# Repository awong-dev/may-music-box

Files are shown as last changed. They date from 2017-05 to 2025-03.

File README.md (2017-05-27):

# May Music Box

This is a little project I made for my daughter. It's an
mp3 player that reads off an SD-card that's built to
replace the guts of a Munchkin Mozart Music Cube.

Why do this? Cause electronic beepy toys for toddlers
are sooo much better if you can control what gets played
on them. :)

## Features
  * Super low power draw. Inactive, draws around 210uA. Active ~50-60mA. With a 1200mAH battery, that's ~8 months of sleep (not really since the battery will leak), or 20 hours of play on one charge.
  * Hardware button debounce. Cuz I could.
  * LEDs that act ike Peak-meter to give your toddler the authentic club feel.
  * Way too much love and sweat put into buliding this thing.
  * The word "mayberry" is printed on the PCB. :)

## What's in this repository
  * Arduino sketch for the MCU that handles the input buttons and playback.
  * vdsp4 assembly code for handling mono downmix, and LED pulsing in of the VS1053b chip
  * Eagle files for the contol PCB.

## Quirks
  * There is a fork of the Adafruit vs1053b library. The mainline library has (multiple) synchronization bugs that lead to corrupted state. This fork fixes the major ones. Remove once upstream merges the fixes.

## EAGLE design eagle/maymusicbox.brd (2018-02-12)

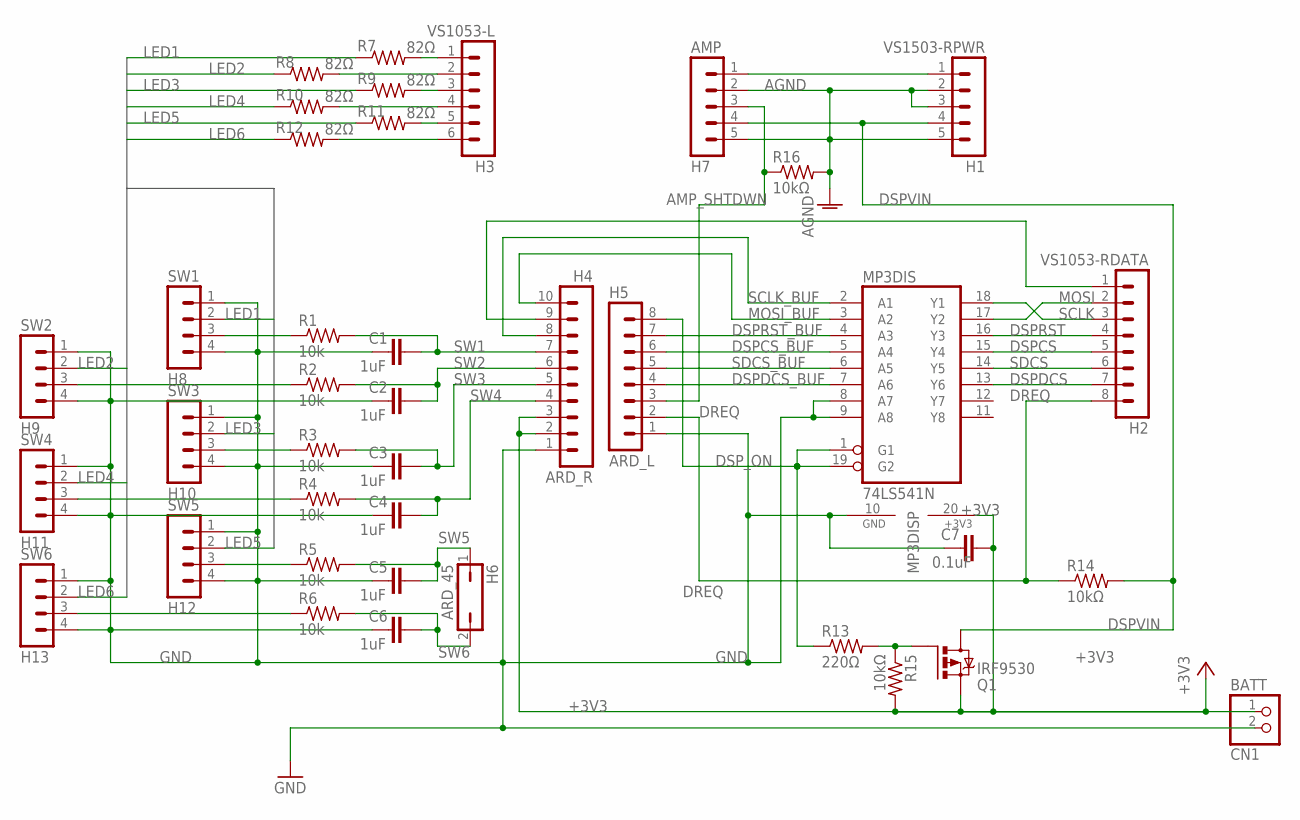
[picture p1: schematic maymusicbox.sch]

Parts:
C1, C2, C3, C4, C5, C6: 1uF; C025-025X050
C7: 0.1uF; C025-025X050
CN1: BATT; JST-PH-2-THM
H1: VS1503-RPWR; MA05-1
H2: VS1053-RDATA; MA08-1
H3: VS1053-L; MA06-1
H4: ARD_R; MA10-1
H5: ARD_L; MA08-1
H6: ARD_45; JP1
H7: AMP; MA05-1
H8: SW1; MA04-1
H9: SW2; MA04-1
H10: SW3; MA04-1
H11: SW4; MA04-1
H12: SW5; MA04-1
H13: SW6; MA04-1
MP3DIS: 74LS541N; DIL20
Q1: IRF9530; TO220BV
R1, R2, R3, R4, R5, R6: 10k; 0207/2V
R7, R8, R9, R10, R11, R12: 82Ω; 0207/2V
R13: 220Ω; 0207/2V
R14, R15, R16: 10kΩ; 0207/2V

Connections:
+3V3: C7.2, CN1.1 (2), H4.2, H4.3, MP3DIS.20 (+3V3), Q1.S, R15.2
A+: H1.1, H7.1
AGND: H1.2, H1.3, H1.5, H7.2, H7.5, R16.2
AMP_SHTDWN: H5.3, H7.3, R16.1
DREQ: H2.8, H5.2, R14.1
DSPCS: H2.5, MP3DIS.15 (Y4)
DSPCS_BUF: H5.6, MP3DIS.5 (A4)
DSPDCS: H2.7, MP3DIS.13 (Y6)
DSPDCS_BUF: H5.4, MP3DIS.7 (A6)
DSPRST: H2.4, MP3DIS.16 (Y3)
DSPRST_BUF: H5.7, MP3DIS.4 (A3)
DSPVIN: H1.4, H7.4, Q1.D, R14.2
DSP_ON: H5.8, MP3DIS.1 (G1), MP3DIS.19 (G2), R13.1
GND: C1.1, C2.1, C3.1, C4.1, C5.1, C6.1, C7.1, CN1.2 (1), H4.1, H5.1, H8.1, H8.4, H9.1, H9.4, H10.1, H10.4, H11.1, H11.4, H12.1, H12.4, H13.1, H13.4, MP3DIS.8 (A7), MP3DIS.9 (A8), MP3DIS.10 (GND)
LED1: H8.2, R7.1
LED2: H9.2, R8.1
LED3: H10.2, R9.1
LED4: H11.2, R10.1
LED5: H12.2, R11.1
LED6: H13.2, R12.1
MISO: H2.1, H4.9
MOSI: H2.2, MP3DIS.17 (Y2)
MOSI_BUF: H4.10, MP3DIS.3 (A2)
unnamed: H3.1, R7.2
unnamed: H3.2, R8.2
unnamed: Q1.G, R13.2, R15.1
unnamed: H3.3, R9.2
unnamed: H3.4, R10.2
unnamed: H3.5, R11.2
unnamed: H3.6, R12.2
unnamed: H10.3, R3.1
unnamed: H9.3, R2.1
unnamed: H8.3, R1.1
unnamed: H11.3, R4.1
unnamed: H12.3, R5.1
unnamed: H13.3, R6.1
SCLK: H2.3, MP3DIS.18 (Y1)
SCLK_BUF: H4.8, MP3DIS.2 (A1)
SDCS: H2.6, MP3DIS.14 (Y5)
SDCS_BUF: H5.5, MP3DIS.6 (A5)
SW1: C1.2, H4.7, R1.2
SW2: C2.2, H4.6, R2.2
SW3: C3.2, H4.5, R3.2
SW4: C4.2, H4.4, R4.2
SW5: C5.2, H6.1, R5.2
SW6: C6.2, H6.2, R6.2

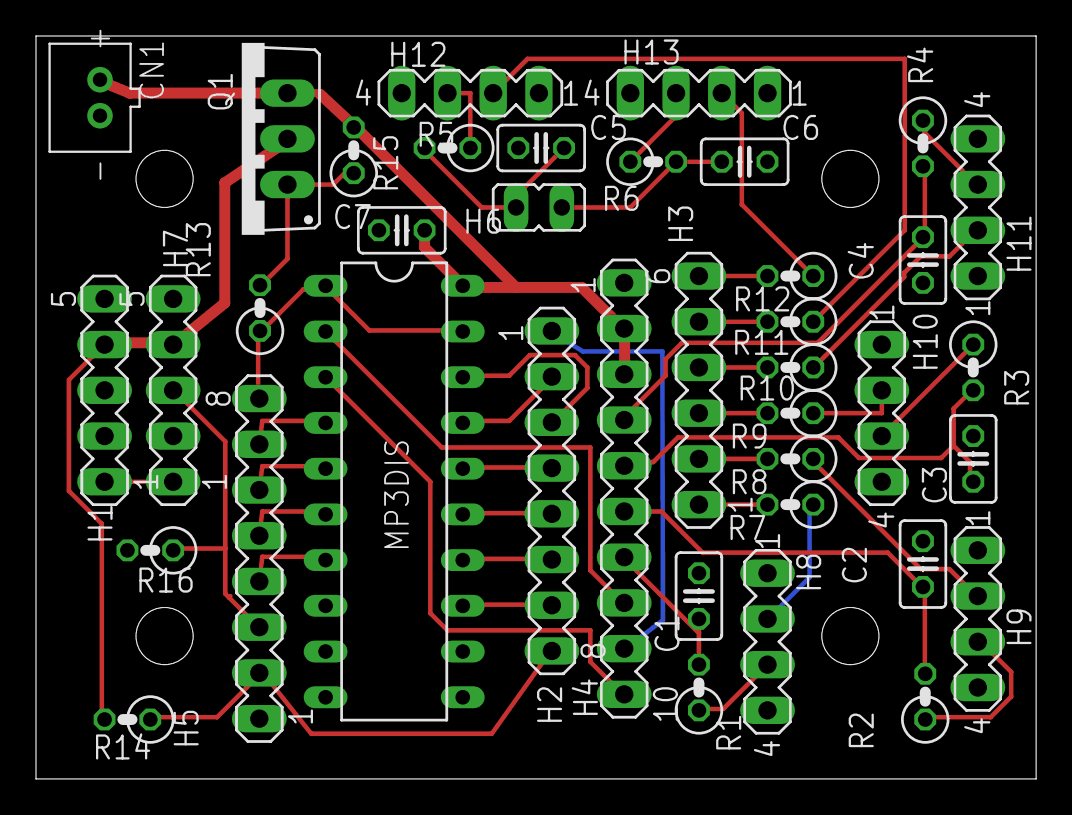
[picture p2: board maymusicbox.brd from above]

Board: 2 copper layers, 55.6 x 41.3 mm, 39 parts (0 on the bottom side), 46 nets.

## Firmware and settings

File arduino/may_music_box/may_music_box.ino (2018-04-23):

/***************************************************
  This is an example for the Adafruit VS1053 Codec Breakout

  Designed specifically to work with the Adafruit VS1053 Codec Breakout
  ----> https://www.adafruit.com/products/1381

  Adafruit invests time and resources providing this open source code,
  please support Adafruit and open-source hardware by purchasing
  products from Adafruit!

  Written by Limor Fried/Ladyada for Adafruit Industries.
  BSD license, all text above must be included in any redistribution
 ****************************************************/

// Battery Cavity:
//  2.5" deep
//  2" wide
//  0.75" tall

// include SPI, MP3 and SD libraries
#include <SPI.h>
#include <SD.h>
#include "Adafruit_VS1053.h"
#include <LowPower.h>
#include <avr/power.h>
#include <avr/sleep.h>

//#define NDEBUG 0
#define DEV_BOARD 0


#if DEV_BOARD == 0
// These are the pins used for the music maker breakout
#  define VS1053bRESET  8      // VS1053 reset pin
#  define VS1053bCS     7      // VS1053 chip select pin (output)
#  define VS1053bDCS    4      // VS1053 Data/command select pin (output)
#  define VS1053bPOWER  9      // PFET that disables VCC to shield.

// These are common pins between breakout and shield
#  define CARDCS 6     // Card chip select pin

// DREQ should be an Int pin, see http://arduino.cc/en/Reference/attachInterrupt
#  define DREQ 2       // VS1053 Data request, ideally an Interrupt pin

// AMP Controls.
#  define AMP_POWER  3         // Turn on and off the AMP before cutting power to stop "pop"
#  define AMP_SHUTDOWN_US 1000  // Microsends post shutdown switch to stablize amp.

#else 
// These are the pins used for the music maker shield
#  define VS1053bRESET  -1      // VS1053 reset pin
#  define VS1053bCS     7      // VS1053 chip select pin (output)
#  define VS1053bDCS    6      // VS1053 Data/command select pin (output)
#  define VS1053bPOWER  8      // PFET that disables VCC to shield.

// These are common pins between breakout and shield
#  define CARDCS 4     // Card chip select pin

// DREQ should be an Int pin, see http://arduino.cc/en/Reference/attachInterrupt
#  define DREQ 3       // VS1053 Data request, ideally an Interrupt pin

#  define AMP_POWER  2         // Turn on and off the AMP before cutting power to stop "pop"
#  define AMP_SHUTDOWN_US 1000  // Microsends post shutdown switch to stablize amp.
#endif


#ifdef NDEBUG
#  define DEBUG_PRINT(x, ...)
#  define DEBUG_PRINTLN(x, ...)
#else
#  define DEBUG_PRINT(x, args...) Serial.print(x, ##args)
#  define DEBUG_PRINTLN(x, args...) Serial.println(x, ##args)
#endif

Adafruit_VS1053_FilePlayer musicPlayer =
  Adafruit_VS1053_FilePlayer(VS1053bRESET, VS1053bCS, VS1053bDCS, DREQ, CARDCS);
static boolean isDspOn = false;
static volatile boolean isSdInit = false;

#define NUM_SONGS 6
static const char* files[NUM_SONGS] = {
  "p.mp3",
  "b.mp3",
  "o.mp3",
  "y.mp3",
  "r.mp3",
  "g.mp3",
};

// Button control inputs
#define RED_BUTTON A5
#define GREEN_BUTTON A4
#define YELLOW_BUTTON A3
#define PURPLE_BUTTON A2
#define BLUE_BUTTON A1
#define ORANGE_BUTTON A0

// LED map, cause I wired one of the harnesses wrong. grr. argh.
const int buttonLedMap[6] = {
  0,  // Red
  1,  // Green
  2,  // Yellow
  3,  // Orange
  5,  // Blue
  4,  // Purple
};


enum PLayCommand {
  NO_COMMAND = 0,
  PLAY_SONG = 1,
};
static volatile byte playCommand = PLAY_SONG;
static volatile unsigned char commandCount = 0;
static volatile byte buttonState = 0;

ISR(PCINT1_vect) {
  byte newButtonState = PINC;
  // Interrupts are triggered on down and up edges. Ignore when everything is up.
  if ((newButtonState & 0x3F) != 0x3F) {
    playCommand = PLAY_SONG;
    buttonState = newButtonState;
    commandCount = commandCount + 1;
  }
  PCICR &= ~_BV(1);
}

//// VS1053b

#define SKIP_PLUGIN_VARNAME
const PROGMEM uint16_t vs1053b_patches[] = { 
//#include "/Users/awong/Desktop/vlsi/awong-ledtest/ledtest-plugin.h"
#include "/Users/awong/Desktop/vlsi/may-music/may-music-vs1053b-plugin.h"
};
#undef SKIP_PLUGIN_VARNAME

////

static void ErrorSleepForever(void);

static void inline PowerOnDsp(void) {
  isDspOn = true;
  
  digitalWrite(AMP_POWER, HIGH);
  delayMicroseconds(AMP_SHUTDOWN_US);
  DEBUG_PRINTLN(F("AMP Powered On"));

  digitalWrite(VS1053bPOWER, LOW);
  // Per VS1053 10.2, Hardware Reset, DREQ is low for about 22000 clocks.
  // At 12Mhz, that's 1.8ms. Give 4 just for good measure.
  delay(4);
  DEBUG_PRINTLN(F("DSP Powered On"));

  initMp3Shield();
}

static void inline PowerOffDsp(void) {
  DEBUG_PRINTLN("DSP Powered Off");
  /* Turn on MP3 shield */
  detachInterrupt(DREQ);
  digitalWrite(AMP_POWER, LOW);
  delayMicroseconds(AMP_SHUTDOWN_US);
  digitalWrite(VS1053bPOWER, HIGH);
  isDspOn = false;
}

static void initMp3Shield() {
  // initialise the music player
  if (!musicPlayer.begin()) {
    DEBUG_PRINTLN(F("Couldn't find VS1053, do you have the right pins defined?"));
    while(1);
    ErrorSleepForever();
  }
  DEBUG_PRINTLN(F("VS1053 found"));

  // Set volume for left, right channels. lower numbers == louder volume!
  // 90 seems like a good amplified volume.
  enum {
    VOL_INSANE = 10, // 70mA during playback.  .21mA sleeping.
    VOL_HIGH = 20,
    VOL_NORMAL = 25,  // Emprical testing for "loud enough"
    VOL_MED = 90,   // Seems to be about 2mA less than HIGH ode.
    VOL_LOW = 120,
  };
  musicPlayer.setVolume(VOL_NORMAL, VOL_NORMAL);

  DEBUG_PRINT(F("isSdInit: "));
  DEBUG_PRINTLN(isSdInit, BIN);
  if (!SD.begin(CARDCS)) {
    if (!isSdInit) {
      DEBUG_PRINTLN(F("SD failed, or not present"));
      DEBUG_PRINTLN(F("SD failed, or not present"));
      DEBUG_PRINTLN(F("SD failed, or not present"));
      DEBUG_PRINTLN(F("SD failed, or not present"));
      ErrorSleepForever();
    }
    // Second inits always generates an error from the library, but it is required.
  } else {
    isSdInit = true;
  }
  DEBUG_PRINTLN(F("SD OK!"));

  // This option uses a pin interrupt. No timers required! But DREQ
  // must be on an interrupt pin. For Uno/Duemilanove/Diecimilla
  // that's Digital #2 or #3
  // See http://arduino.cc/en/Reference/attachInterrupt for other pins
  // *** This method is preferred
  if (!musicPlayer.useInterrupt(VS1053_FILEPLAYER_PIN_INT)) {
    DEBUG_PRINTLN(F("DREQ pin is not an interrupt pin"));
    ErrorSleepForever();
  }

  musicPlayer.applyPatch(vs1053b_patches, PLUGIN_SIZE);
  musicPlayer.sciWrite(VS1053_SCI_AIADDR, 0x50);
  delay(1);    while (! musicPlayer.readyForData() );
}

static void ErrorSleepForever(void) {
  DEBUG_PRINTLN(F("Error state. Sleep Forever"));
  PowerOffDsp();
  while(1) {
    LowPower.powerDown(SLEEP_FOREVER, ADC_OFF, BOD_OFF);
  }
}


//// Power Code.

static void sleepTillInt()         // here we put the arduino to sleep
{
#ifndef NDEBUG
  // Clear the Serial buffer so there isn't crap.
  Serial.flush();

  while (!(UCSR0A & (1 << UDRE0)))  // Wait for empty transmit buffer
    UCSR0A |= 1 << TXC0;  // mark transmission not complete
  while (!(UCSR0A & (1 << TXC0)));   // Wait for the transmission to complete
#endif

  //power_spi_disable();
  
  LowPower.powerDown(SLEEP_FOREVER, ADC_OFF, BOD_OFF);
  
  //power_spi_enable();
}

void setup() {
#ifndef NDEBUG
  Serial.begin(9600);
  DEBUG_PRINTLN(F("May Music Box"));
#endif

  // Start with DSP powered down. It is powered up on button push.
  pinMode(VS1053bPOWER, OUTPUT);
  pinMode(AMP_POWER, OUTPUT);
  PowerOffDsp();

  SPI.begin();

  // Shut down bunches of modules we don't use.
  // See PRR register 14.12.3.
  power_adc_disable();
#ifdef NDEBUG
  // No UART for console outside of debug mode.
  power_usart0_disable();
#endif
  power_twi_disable();
  DEBUG_PRINTLN("Unused Arduino Modules disabled");

  /*** Setup the control buttons here ***/
  pinMode(RED_BUTTON, INPUT_PULLUP);
  pinMode(GREEN_BUTTON, INPUT_PULLUP);
  pinMode(YELLOW_BUTTON, INPUT_PULLUP);
  pinMode(PURPLE_BUTTON, INPUT_PULLUP);
  pinMode(BLUE_BUTTON, INPUT_PULLUP);
  pinMode(ORANGE_BUTTON, INPUT_PULLUP);
  delay(30);  // Give 30 ms for the debounce capacitors to charge. 1uF + 30k at 3.3v should charge in 23ms.

  // Ensure all unused pins are in output state.
  // TODO(awong): Fix this.

  // Clear and enable Pinchange Interrupt Vector 1 for the analog pins A0-A5.
  PCIFR |= _BV(1);
  PCICR |= _BV(1);
  PCMSK1 |= 0x3F;
  DEBUG_PRINTLN(F("Button interrupts configured"));
}

void loop() {
  boolean hasNewSong = false;

  // Read the command.
  switch (playCommand) {
    case PLAY_SONG:
      hasNewSong = true;
      playCommand = NO_COMMAND;
      break;

    default:
      // Do nothing.
      break;
  }

  // Start playing a file, then we can do stuff while waiting for it to finish
  PCICR |= _BV(1);
  unsigned char lastButtonState = buttonState;
  if (hasNewSong && lastButtonState) {
    DEBUG_PRINTLN(F("Playing Song"));
    if (!isDspOn) {
      PowerOnDsp();
    }
    DEBUG_PRINTLN(commandCount);

    if (musicPlayer.playingMusic) {
      musicPlayer.stopPlaying();
    }

    DEBUG_PRINT(F("Button state:"));
    DEBUG_PRINT(lastButtonState, BIN);
    DEBUG_PRINT(F(", "));
    int curSong = NUM_SONGS - 1;
    while (lastButtonState & 0x1) {
      lastButtonState >>= 1;
      --curSong;
    }

    DEBUG_PRINT(F("Cur Song: "));
    DEBUG_PRINTLN(curSong);
    if (curSong < NUM_SONGS) {
      const char* currentFile = files[curSong];

      DEBUG_PRINT(F("Current file: "));
      DEBUG_PRINTLN(currentFile);
      int led_value = buttonLedMap[5 - curSong];
      DEBUG_PRINT(F("Led Value: "));
      DEBUG_PRINTLN(led_value);
      musicPlayer.sciWrite(VS1053_SCI_AICTRL0, led_value);
      if (! musicPlayer.startPlayingFile(currentFile)) {
        DEBUG_PRINT(F("Could not open file "));
      }
    
      DEBUG_PRINTLN(F("Started playing"));
    } else {
      DEBUG_PRINT(F("!! Out or range song: "));
      DEBUG_PRINTLN(curSong);
    }
  }

  if (musicPlayer.playingMusic) {
#ifndef NDEBUG
    static unsigned int counter = 0;
    if (counter++ % 50 == 0) {
      DEBUG_PRINT(F("."));
    }
#endif
  } else if (isDspOn) {
#ifndef NDEBUG
    static unsigned int counter = 0;
    if (counter++ % 50 == 0) {
      DEBUG_PRINT(F("_s_"));
    }
#endif
    PowerOffDsp();
  }

  // Wait until something wakes us.
  sleepTillInt();
}

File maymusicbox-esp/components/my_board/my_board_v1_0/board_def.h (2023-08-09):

/*
 * ESPRESSIF MIT License
 *
 * Copyright (c) 2020 <ESPRESSIF SYSTEMS (SHANGHAI) CO., LTD>
 *
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
 */

#ifndef _AUDIO_BOARD_DEFINITION_H_
#define _AUDIO_BOARD_DEFINITION_H_

#define BUTTON_VOLUP_ID           0     /* You need to define the GPIO pins of your board */
#define BUTTON_VOLDOWN_ID         1     /* You need to define the GPIO pins of your board */
#define BUTTON_MUTE_ID            2     /* You need to define the GPIO pins of your board */
#define BUTTON_SET_ID             3     /* You need to define the GPIO pins of your board */
#define BUTTON_MODE_ID            4     /* You need to define the GPIO pins of your board */
#define BUTTON_PLAY_ID            5     /* You need to define the GPIO pins of your board */
#define PA_ENABLE_GPIO            6     /* You need to define the GPIO pins of your board */
#define ADC_DETECT_GPIO           7     /* You need to define the GPIO pins of your board */
#define BATTERY_DETECT_GPIO       8     /* You need to define the GPIO pins of your board */

#define SDCARD_OPEN_FILE_NUM_MAX  5

/**
 * @brief SDCARD Function Definition
 */
#define FUNC_SDCARD_EN             (0)
#define SDCARD_OPEN_FILE_NUM_MAX    5
#define SDCARD_INTR_GPIO            9     /* You need to define the GPIO pins of your board */

#define ESP_SD_PIN_CLK              -1
#define ESP_SD_PIN_CMD              -1
#define ESP_SD_PIN_D0               -1
#define ESP_SD_PIN_D3               -1

extern audio_hal_func_t AUDIO_NEW_CODEC_DEFAULT_HANDLE;

#define AUDIO_CODEC_DEFAULT_CONFIG(){                   \
        .adc_input  = AUDIO_HAL_ADC_INPUT_LINE1,        \
        .dac_output = AUDIO_HAL_DAC_OUTPUT_ALL,         \
        .codec_mode = AUDIO_HAL_CODEC_MODE_BOTH,        \
        .i2s_iface = {                                  \
            .mode = AUDIO_HAL_MODE_SLAVE,               \
            .fmt = AUDIO_HAL_I2S_NORMAL,                \
            .samples = AUDIO_HAL_48K_SAMPLES,           \
            .bits = AUDIO_HAL_BIT_LENGTH_16BITS,        \
        },                                              \
};

#define INPUT_KEY_NUM     4             /* You need to define the number of input buttons on your board */

#define INPUT_KEY_DEFAULT_INFO() {                      \
    {                                                   \
        .type = PERIPH_ID_ADC_BTN,                      \
        .user_id = INPUT_KEY_USER_ID_VOLUP,             \
        .act_id = BUTTON_VOLUP_ID,                      \
    },                                                  \
    {                                                   \
        .type = PERIPH_ID_ADC_BTN,                      \
        .user_id = INPUT_KEY_USER_ID_VOLDOWN,           \
        .act_id = BUTTON_VOLDOWN_ID,                    \
    },                                                  \
    {                                                   \
        .type = PERIPH_ID_ADC_BTN,                      \
        .user_id = INPUT_KEY_USER_ID_MUTE,              \
        .act_id = BUTTON_MUTE_ID,                       \
    },                                                  \
    {                                                   \
        .type = PERIPH_ID_ADC_BTN,                      \
        .user_id = INPUT_KEY_USER_ID_SET,               \
        .act_id = BUTTON_SET_ID,                        \
    },                                                  \
}

#define BOARD_PA_GAIN 1

#endif

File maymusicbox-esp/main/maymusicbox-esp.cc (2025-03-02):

#include <stdio.h>

#include <string.h>
#include "freertos/FreeRTOS.h"
#include "freertos/task.h"

#include "sdkconfig.h"

#include <sys/unistd.h>
#include <sys/stat.h>

#include "esp_sleep.h"
#include "esp_vfs_fat.h"
#include "sdmmc_cmd.h"

#include "audio_player.h"
#include "buttons.h"
#include "led.h"
#include "logging.h"
#include "wake.h"

// Look at this as an example of 2 outputs.
// https://github.com/espressif/esp-adf/blob/master/examples/advanced_examples/http_play_and_save_to_file/main/http_play_and_save_to_file.c

// Mounts the SD Card connected to VSPI default pins on /sdcard
sdmmc_card_t* mount_sdcard() {
  ESP_LOGI(TAG, "Configuring SD card GPIO");
  static const gpio_config_t sd_out_pins = {
    .pin_bit_mask = (
        (1ULL << GPIO_NUM_21) |
        (1ULL << GPIO_NUM_22) |
        (1ULL << GPIO_NUM_23)
        ),
    .mode = GPIO_MODE_OUTPUT,
    .pull_up_en = GPIO_PULLUP_DISABLE,
    .pull_down_en = GPIO_PULLDOWN_DISABLE,
    .intr_type = GPIO_INTR_DISABLE
  };
  ESP_ERROR_CHECK(gpio_config(&sd_out_pins));

  static const char* kMountPoint = "/sdcard";

  esp_vfs_fat_sdmmc_mount_config_t mount_config = {
      .format_if_mount_failed = false,
      .max_files = 5,
      .allocation_unit_size = 16 * 1024
  };

  ESP_LOGI(TAG, "Initializing SD card");

  // Use settings defined above to initialize SD card and mount FAT filesystem.
  // Note: esp_vfs_fat_sdmmc/sdspi_mount is all-in-one convenience functions.
  // Please check its source code and implement error recovery when developing
  // production applications.
  ESP_LOGI(TAG, "Using SPI peripheral");

  // By default, SD card frequency is initialized to SDMMC_FREQ_DEFAULT (20MHz)
  // For setting a specific frequency, use host.max_freq_khz (range 400kHz - 20MHz for SDSPI)
  // Example: for fixed frequency of 10MHz, use host.max_freq_khz = 10000;
  sdmmc_host_t host = SDSPI_HOST_DEFAULT();
  host.slot = SPI3_HOST;

  spi_bus_config_t bus_cfg = {};
  bus_cfg.mosi_io_num = GPIO_NUM_22;
  bus_cfg.miso_io_num = GPIO_NUM_19;
  bus_cfg.sclk_io_num = GPIO_NUM_21;
  bus_cfg.quadwp_io_num = -1;
  bus_cfg.quadhd_io_num = -1;
  bus_cfg.max_transfer_sz = 4000;

  ESP_ERROR_CHECK(spi_bus_initialize(static_cast<spi_host_device_t>(host.slot), &bus_cfg, SDSPI_DEFAULT_DMA));

  // This initializes the slot without card detect (CD) and write protect (WP) signals.
  // Modify slot_config.gpio_cd and slot_config.gpio_wp if your board has these signals.
  sdspi_device_config_t slot_config = SDSPI_DEVICE_CONFIG_DEFAULT();
  slot_config.gpio_cs = GPIO_NUM_23;
  slot_config.host_id = static_cast<spi_host_device_t>(host.slot);

  ESP_LOGI(TAG, "Mounting filesystem");

  sdmmc_card_t* card = NULL;
  ESP_ERROR_CHECK(esp_vfs_fat_sdspi_mount(kMountPoint, &host, &slot_config,
        &mount_config, &card));

  return card;
}

void run_buttons(void* param) {
  Buttons* buttons = static_cast<Buttons*>(param);
  buttons->process_buttons();
}

extern "C" void app_main(void)
{
  esp_sleep_wakeup_cause_t cause = esp_sleep_get_wakeup_cause();
  // Unused pin. Set to output.
  // TODO: consider isolating.
  gpio_set_direction(GPIO_NUM_12, GPIO_MODE_OUTPUT);

  Led led;

  init_ulp();
  if (cause != ESP_SLEEP_WAKEUP_ULP) {
    ESP_LOGE(TAG, "FULL Reset: %d", cause);
    start_ulp();
    led.flare_all_and_follow();
    vTaskDelay(500 / portTICK_PERIOD_MS);

    // HACK: Sleep right away after first start of ULP. Otherwise something goes wrong
    // with the button reading.
    ESP_LOGI(TAG, "Initial sleep");
    enter_sleep();
  }

  mount_sdcard();
  Buttons buttons(&led);

  vTaskDelay(500 / portTICK_PERIOD_MS);
  xTaskCreatePinnedToCore(&run_buttons, "button_task", 4096, &buttons, 5, NULL, 0);
  while (1) {
    vTaskDelay(portMAX_DELAY);
  }
}

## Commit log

2017-04-15 Fix the loops so they work. Ugh.
    Somehow I thought the delay slot held the operation that affected the
    jump. Of course, that makes no sense since the delay slot is the
    pipelined instruction that has already been fetched meaning the jump has
    already modified the PC for pre-fecth before it executes. This is what
    happens when you only code after the kid goes down. Grr.
2017-04-18 Works with led flashing.
2017-05-24 Reasonable visual delay.
    Unfortuntly, the PWM frequency of 300hz means the sample is
    happening at 76800 Hz in the current code which is ludicrous.
    Sampling should happen at each PWM cycle edge instead. Change
    in next update.
2017-05-24 Simplified sample at 300hz
2017-05-27 Add arduino and eagle files.
    [maymusicbox.brd, maymusicbox.sch]
2018-02-12 Fix Schematic + Part to have 0 error issues
    [maymusicbox.brd, maymusicbox.sch]
2018-04-23 Updated for V2 board, including pin wiring error
    [may_music_box.ino]
2023-04-14 Building out most of the button control code.
2023-04-19 Clean up button events to fire consistently.
2023-04-20 connect button to player
2023-04-20 LED pulse_active() start
2023-04-22 Most of led wire up done too now.
2023-04-22 Migrate from deprecated timer APIs
2023-04-24 Complete the LED acitons. There's something wrong with the timer_isr callback registration.
    [audio_player.cc, led.cc, maymusicbox-esp.cc]
2023-04-24 Go back to newer timer_isr registration. Still hangs on button-down.
2023-04-24 Move to single-channel per led
2023-04-30 Got at 300hz follow going!
2023-05-02 Add ULP button debounce program
2023-05-04 ULP Button histories now correct!
    [maymusicbox-esp.cc]
2023-05-06 Button fully in ULP
2023-05-08 Doesn't work and garbled
    [audio_player.cc]
2023-05-10 Cleaned up a lot. Missing first button press
    [audio_player.cc, led.cc, maymusicbox-esp.cc]
2023-05-10 Cleaner button interface
2023-05-11 Reuse first gpio sample.
2023-05-12 cleanup Led class code
2023-05-12 Redo the led command logic
2023-05-15 Clean-up LED hold logic
2023-05-15 Fix Led ordering
2023-05-24 Clean-up button state publishing
2023-05-24 Correct sleep logic and poll
    [audio_player.cc, maymusicbox-esp.cc, wake.cc]
2023-08-06 Tweak led values to look pretty
2023-08-20 Plays continuously without sleeping and no crashes
    [audio_player.cc, led.cc, wake.cc]
2025-03-02 Stably works again.
    Reenabled long fat filenames. (doh)
    Move the song seleciton out of the button scan to avoid multiple
    calls to start/stop when a button is pushed.
    Remove the call to time(nullptr) in wake_incr() which avoids an
    internal lock that would otherwise cause a deadlock if the interrupt
    handler executes while the audio playback is occurring. (double doh).
    There is still a race when you hit the button too fast, but this
    at least works semi stably.
    [audio_player.cc, led.cc, maymusicbox-esp.cc]
